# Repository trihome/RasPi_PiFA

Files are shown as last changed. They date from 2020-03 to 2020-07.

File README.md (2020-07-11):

# PiFA HAT

This board will make it possible to connect equipment used at the factory  (ex: switches, sensors, relays, at all...) to your Raspberry Pi.
It can isolate connected equipments from Raspberry Pi.

**Note**

Please import this library before using this repository.
https://github.com/trihome/KiCad_MyLibrary

**How to make**

[Manual (Japanese only)](./doc/README_pcb.jp.md)

## [PiFA 8xy](./PiFA_8xy/)

A prototyping board "HAT".
GPIO pins can be freely selected.

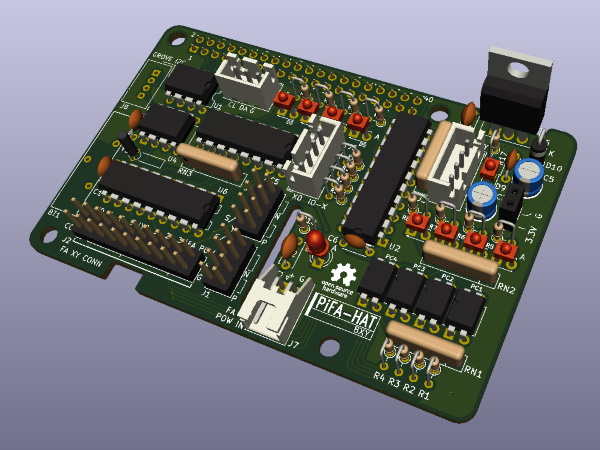
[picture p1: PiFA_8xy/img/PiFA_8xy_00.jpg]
pifa8xy00 3D


- 4 isolated inputs and 4 isolated outputs.
- Selectable Sink(NPN) / Source(PNP)
- I2C-bus voltage-level translator (3.3 to 5 V)
- RTC

## License

This is under [CC-BY-SA](https://creativecommons.org/licenses/by-sa/4.0/).

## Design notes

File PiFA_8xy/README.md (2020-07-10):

# PiFA 8xy

A prototyping board "HAT".

GPIO pins can be freely selected.

[Schematic](./img/PiFA_8xy.pdf)

**Note**

Please import this library before using this repository.
https://github.com/trihome/KiCad_MyLibrary

pifa8xy00 3D
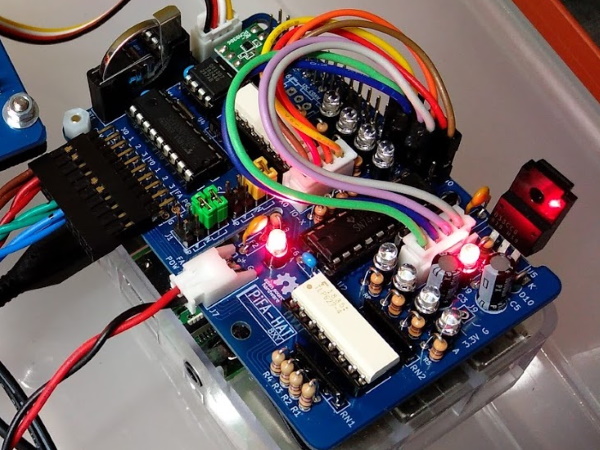
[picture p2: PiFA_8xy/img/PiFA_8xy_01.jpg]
pifa8xy01 Usage


## Spec

- 4 isolated inputs and 4 isolated outputs.
  - J3(Y) is Output, and J5(X) is Input.
  - Connect these connectors to the Raspberry Pi Pins.
  - [J3 and J5: B4B-XH-A(LF)(SN)](http://akizukidenshi.com/catalog/g/gC-12249/)
  - [Raspberry Pi Pins: QI(2550)connectors](http://akizukidenshi.com/catalog/g/gC-12150/)
- Supply 24V power to J7.
  - J2 is Input / Output for FA(24V)
  - Recommended [Terminal block](https://www.togi.co.jp/product/interface/1072/) and [Cables](https://www.togi.co.jp/product/harness-cable/2661/) or QI(2550)connectors.
- Selectable Sink(NPN) / Source(PNP) : J1(Input), J4(Output)
  - U6: Transistor array, you have to choose.
    - J4 = [Sink(NPN)](http://akizukidenshi.com/catalog/g/gI-10669/)
    - J4 = [Source(PNP)](http://akizukidenshi.com/catalog/g/gI-10957/)
- I2C-bus voltage-level translator (3.3 to 5 V)
  - [U1: AE-PCA9306](http://akizukidenshi.com/catalog/g/gM-05452/)
  - I2C Output connector
    - J6: Pin Header (5V)
    - J8: GROVE (5V)
- RTC
  - [U4 : DS1307+](http://akizukidenshi.com/catalog/g/gI-06949/)
  - [BT1: CH243-2032LF](http://akizukidenshi.com/catalog/g/gP-02019/) and CR2032

## Example of use

### Terminal block

- [Terminal block](https://www.togi.co.jp/product/interface/1072/)
- [Cables](https://www.togi.co.jp/product/harness-cable/2661/)

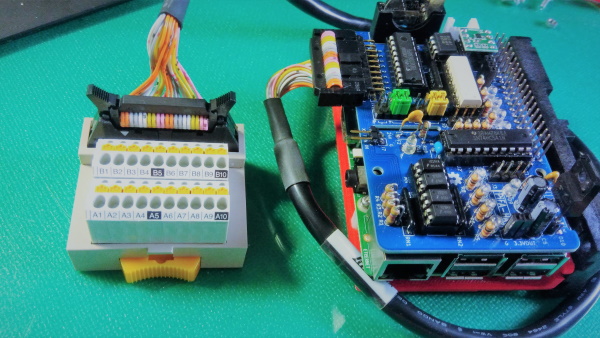
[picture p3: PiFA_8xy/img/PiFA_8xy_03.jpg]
pifa8xy03 Usage

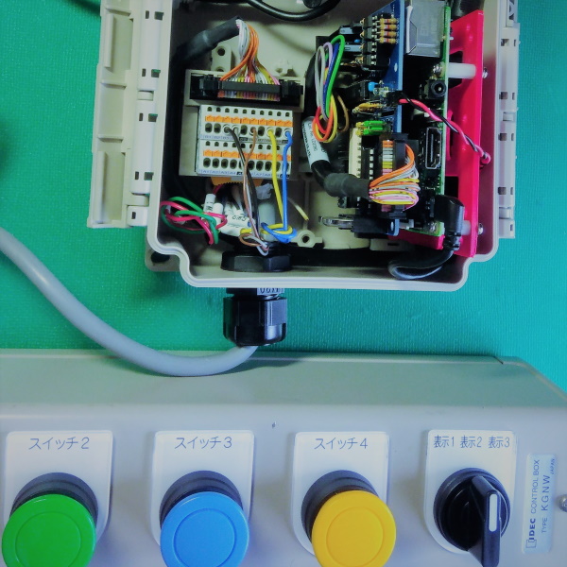
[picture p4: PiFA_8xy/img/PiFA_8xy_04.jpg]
pifa8xy04 Usage


### Stack
If you need more I/O ports, you can increase them by stacking boards.
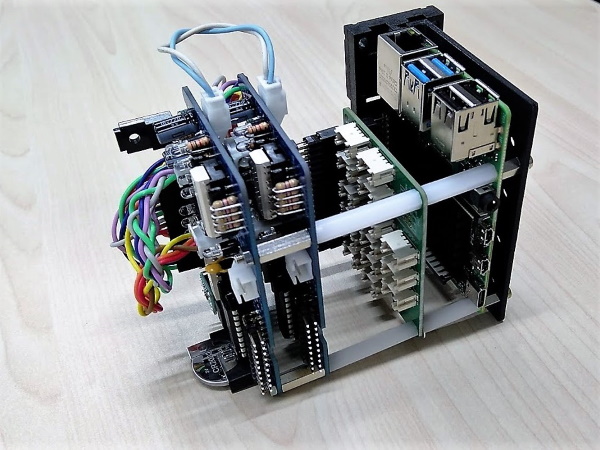
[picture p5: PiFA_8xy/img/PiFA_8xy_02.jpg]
pifa8xy02 Usage

- The board sandwiched in the middle is [Grove Base Hat for Raspberry Pi](http://wiki.seeedstudio.com/Grove_Base_Hat_for_Raspberry_Pi/)
- DIN rail bracket: [example](https://www.takachi-el.co.jp/products/DRA)

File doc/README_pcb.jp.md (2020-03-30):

# 製作方法について

## 部品の入手

大半の部品は、秋月電子通商さんで購入できます。
一部、取り扱いのない部品については、以下から購入可能です。
（端子台などのFA用部品は、勤め先で取引している電材屋さんで購入するのが望ましいです）

|部品名|入手先|通販|
|---|---|---|
|集合抵抗 4P 4.7kΩ|千石電商さん|[リンク](https://www.sengoku.co.jp/mod/sgk_cart/detail.php?code=EEHD-05ST)|
|^|マルツさん|[リンク](https://www.marutsu.co.jp/pc/i/435604/)|
|端子台|マルツさん|[リンク](https://www.marutsu.co.jp/pc/i/1544810/)|
|^|misumiさん|[リンク](https://jp.misumi-ec.com/vona2/detail/222000477644/?HissuCode=PCX-1H20)|
|端子台ケーブル|yahoo shoppingさん|[リンク](https://store.shopping.yahoo.co.jp/akin-do/tao-00009.html)|
||||

## 基板の製作

各ディレクトリ配下に、`gerver`ディレクトリがあるので、この中のファイル一式を、PCB業者に制作依頼します。

（一例）
- [Fusion PCB](https://www.fusionpcb.jp/)
- [P板.com](https://www.p-ban.com/)

### Fusion PCBでの注文手順

※2020年3月時点の手順です。
※費用はPayPalアカウントかクレジットカードで支払います。

1. ユーザー登録
    https://www.fusionpcb.jp/register.html

    [こちら](http://tomokatsu.hatenablog.com/entry/2017/06/14/213324)を参考に、ユーザー登録します。
    
    ※住所は英語表記です。（日本での表記と逆順）

1. gerverディレクトリの中のファイル１０個をZIPで圧縮

1. 発注
    https://www.fusionpcb.jp/fusion_pcb.html

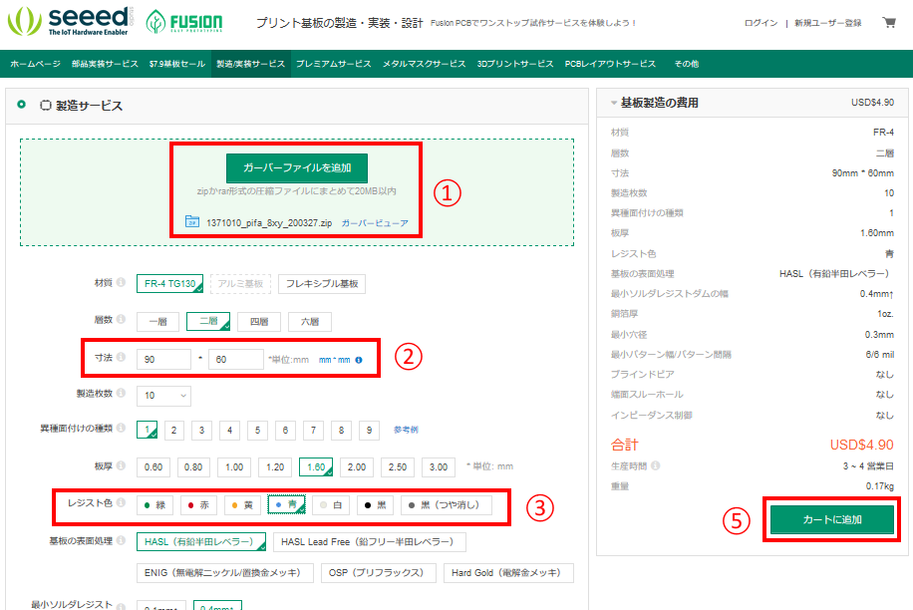
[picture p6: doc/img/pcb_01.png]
pcb01 Usage
    

    1. 「ガーバーファイルを追加」を押して、先ほどのZIPファイルをアップロード
    1. 寸法は 90 x 60 mmを指定
        - 自動で入力される場合もあります
        - 100 x 100 mmサイズ以下かつ、１０枚以下は1ロットの基板費用は$5以下
    1. レジスト色は好きな色を選ぶ（黒つや消しは若干高価）
    1. その他の指定はデフォルトのまま
    1. 「カートに追加」ボタンを押す
    1. カートをクリック
    1. 「お支払いに進む」ボタンを押す
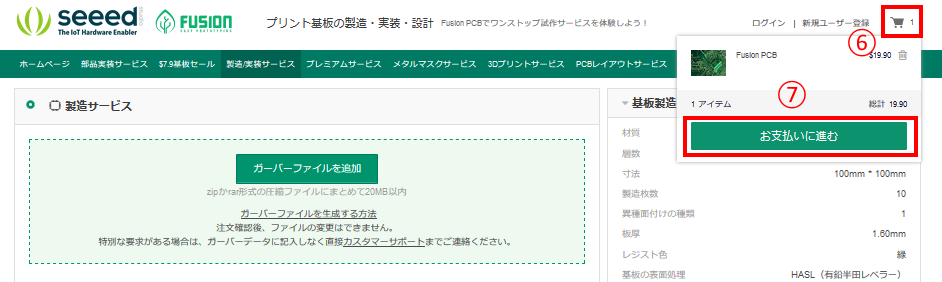
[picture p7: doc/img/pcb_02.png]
    
    1. 「安全な支払いを選択」を押して、（ログインしてない場合は）ここでログイン
    1. 送り先の確認（アカウント情報から紐付けで自動代入）
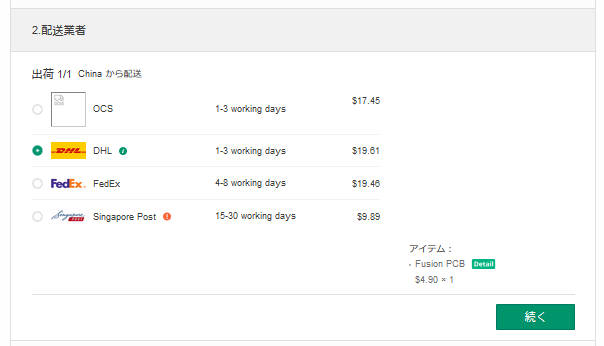
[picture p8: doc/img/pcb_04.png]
    
    1. 配送業者を選ぶ
        - 急ぐときはDHL, FedEx, OCSなどの航空便を選ぶ。送料約$20前後。
    1. 費用を支払う

航空便を使った場合、納期の目安は平常時（中国内での季節のイベントがないとき）で実働5日～10日くらいです。

以上

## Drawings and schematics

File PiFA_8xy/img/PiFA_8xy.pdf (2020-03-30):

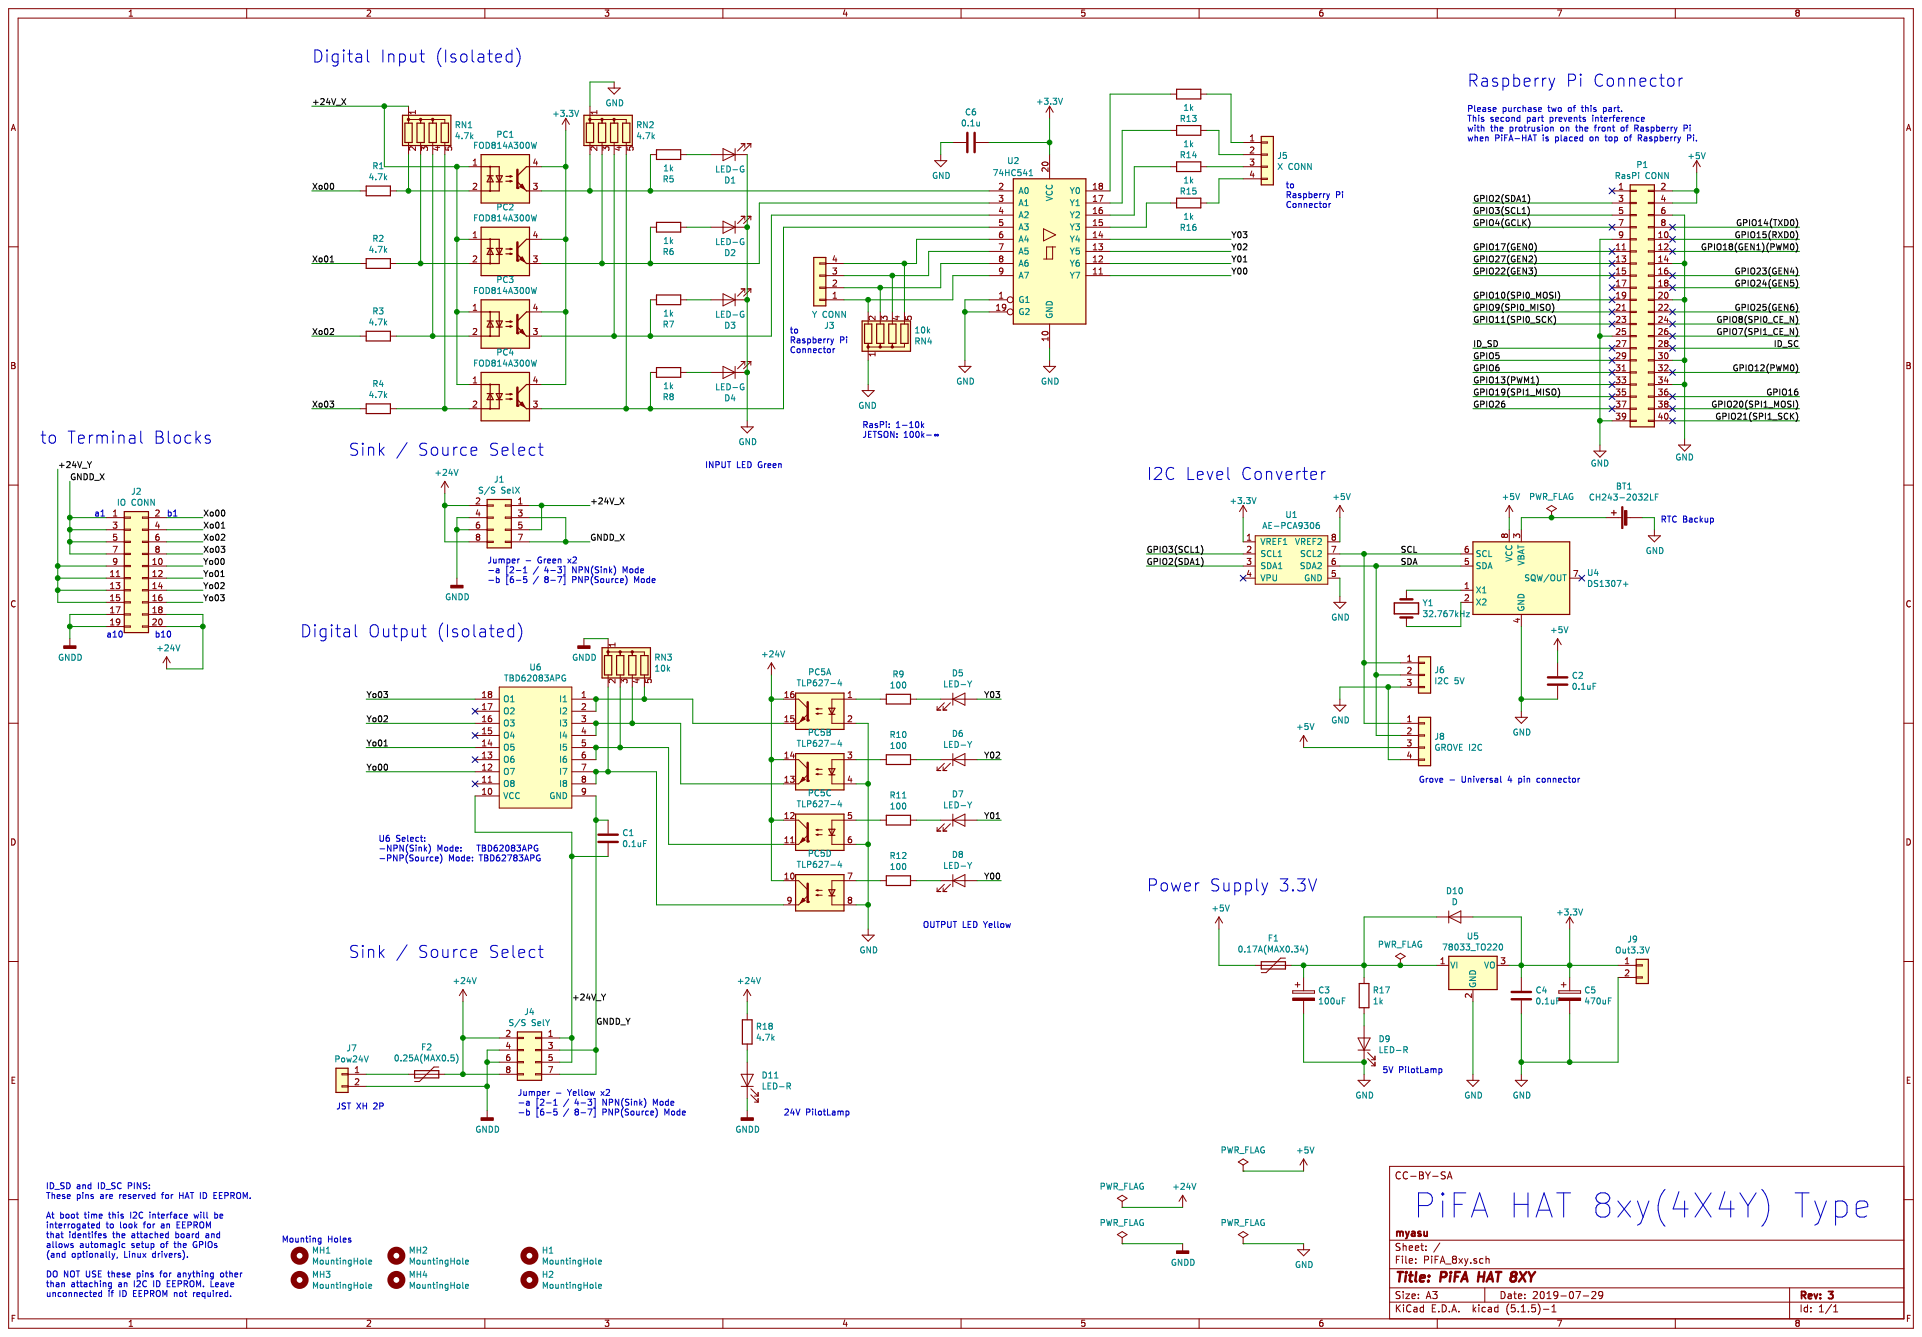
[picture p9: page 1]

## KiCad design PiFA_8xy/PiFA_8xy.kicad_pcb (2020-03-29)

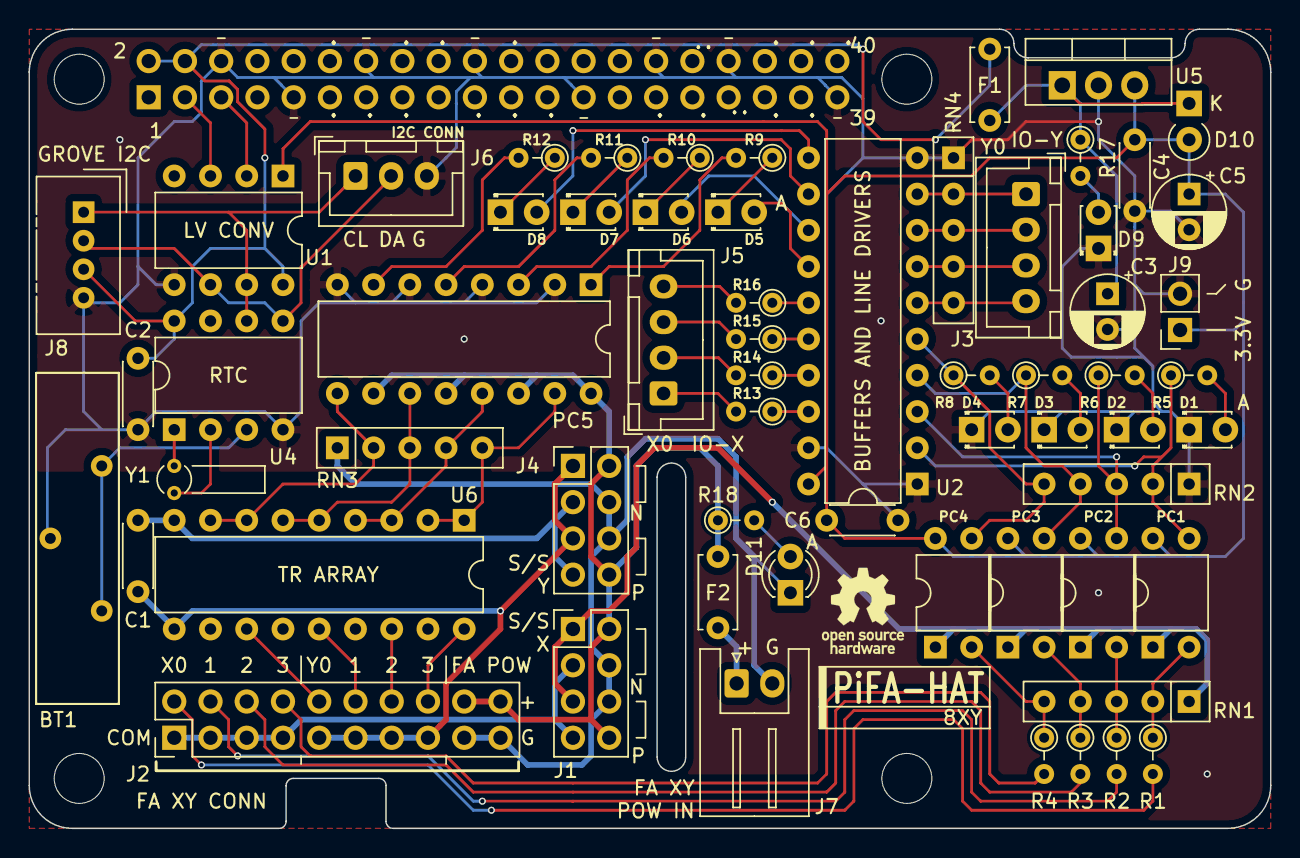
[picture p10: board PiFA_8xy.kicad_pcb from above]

Board: 2 copper layers, 87.0 x 56.0 mm, 69 parts (1 on the bottom side), 68 nets.

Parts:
BT1: CH74-2032LF; BatteryHolder_Keystone_CH74-2032LF
C1, C2, C4: 0.1uF; C_Disc_D4.3mm_W1.9mm_P5.00mm
C3: 100uF; CP_Radial_D5.0mm_P2.50mm
C5: 470uF; CP_Radial_D5.0mm_P2.50mm
C6: 0.1u; C_Disc_D4.3mm_W1.9mm_P5.00mm
D1, D2, D3, D4: LED-G; LED_D1.8mm_W3.3mm_H2.4mm
D5, D6, D7, D8: LED-Y; LED_D1.8mm_W3.3mm_H2.4mm
D9: LED-R; LED_D1.8mm_W3.3mm_H2.4mm
D10: D; D_A-405_P2.54mm_Vertical_KathodeUp
D11: LED-R; LED_D3.0mm
F1: 0.17A(MAX0.34); C_Disc_D5.0mm_W2.5mm_P5.00mm
F2: 0.25A(MAX0.5); C_Disc_D5.0mm_W2.5mm_P5.00mm
H1: MountingHole; OSHW-Logo_5.7x6mm_SilkScreen
H2: MountingHole; CC-BY-SA
J1: S/S SelX; PinHeader_2x04_P2.54mm_Vertical
J2: IO CONN; PinHeader_2x10_P2.54mm_Vertical
J3: Y CONN; JST_XH_B4B-XH-A_1x04_P2.50mm_Vertical
J4: S/S SelY; PinHeader_2x04_P2.54mm_Vertical
J5: X CONN; JST_XH_B4B-XH-A_1x04_P2.50mm_Vertical
J6: I2C 5V; JST_XH_B3B-XH-A_1x03_P2.50mm_Vertical
J7: Pow24V; JST_XH_S2B-XH-A_1x02_P2.50mm_Horizontal
J8: GROVE I2C; NS-Tech_Grove_1x04_P2mm_Vertical
J9: Out3.3V; PinSocket_1x02_P2.54mm_Vertical
MH1, MH2, MH3, MH4: MountingHole; MountingHole_3mm
P1: RasPi CONN; PinSocket_2x20_P2.54mm_Vertical
PC1, PC2, PC3, PC4: FOD814A300W; DIP-4_W7.62mm
PC5: TLP627-4; DIP-16_W7.62mm
R1, R2, R3, R4, R18: 4.7k; R_Axial_DIN0204_L3.6mm_D1.6mm_P2.54mm_Vertical
R5, R6, R7, R8, R13, R14, R15, R16, R17: 1k; R_Axial_DIN0204_L3.6mm_D1.6mm_P2.54mm_Vertical
R9, R10, R11, R12: 100; R_Axial_DIN0204_L3.6mm_D1.6mm_P2.54mm_Vertical
RN1, RN2: 4.7k; R_Array_SIP5
RN3: 10k; R_Array_SIP5
RN4: 1k; R_Array_SIP5
U1: AE-PCA9306; DIP-8_W7.62mm
U2: 74HCT541; DIP-20_W7.62mm
U4: DS1307+; DIP-8_W7.62mm
U5: 78033_TO220; TO-220-3_Vertical
U6: TBD62083APG; DIP-18_W7.62mm
Y1: 32.767kHz; Crystal_Round_D2.0mm_Vertical

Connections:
+3V3: C4.1, C5.1, C6.1, D10.2, J9.1, PC1.4, PC2.4, PC3.4, PC4.4, U1.1, U2.20, U5.3
+5V: C2.1, F1.2, J8.3, P1.2, P1.4, U1.8, U4.8
+24V: F2.1, J1.2, J1.8, J2.18, J2.20, J4.2, J4.8, PC5.10, PC5.12, PC5.14, PC5.16, R18.1
/+24V_X: J1.1, J1.5, PC1.1, PC2.1, PC3.1, PC4.1, RN1.1
/+24V_Y: C1.2, J2.9, J2.11, J2.13, J2.15, J4.1, J4.5, U6.10
/GNDD_X: J1.3, J1.7, J2.1, J2.3, J2.5, J2.7
/GNDD_Y: C1.1, J4.3, J4.7, U6.9
/GPIO2(SDA1): P1.3, U1.3
/GPIO3(SCL1): P1.5, U1.2
/SCL: J6.1, J8.1, U1.7, U4.6
/SDA: J6.2, J8.2, U1.6, U4.5
/Xo00: J2.2, R1.2
/Xo01: J2.4, R2.2
/Xo02: J2.6, R3.2
/Xo03: J2.8, R4.2
/Y00: D8.2, U2.11
/Y01: D7.2, U2.12
/Y02: D6.2, U2.13
/Y03: D5.2, U2.14
/Yo00: J2.10, U6.12
/Yo01: J2.12, U6.14
/Yo02: J2.14, U6.16
/Yo03: J2.16, U6.18
GND: BT1.2, C2.2, C3.2, C4.2, C5.2, C6.2, D1.1, D2.1, D3.1, D4.1, D9.1, J6.3, J8.4, J9.2, P1.6, P1.9, P1.14, P1.20, P1.25, P1.30, P1.34, P1.39, PC5.2, PC5.4, PC5.6, PC5.8, RN2.1, RN4.1, U1.5, U2.1, U2.10, U2.19, U4.4, U5.2
GNDD: D11.1, J1.4, J1.6, J2.17, J2.19, J4.4, J4.6, J7.2, RN3.1
unnamed: BT1.1, U4.3
unnamed: C3.1, D10.1, F1.1, R17.1, U5.1
unnamed: D1.2, R5.2
unnamed: D2.2, R6.2
unnamed: D3.2, R7.2
unnamed: D4.2, R8.2
unnamed: D5.1, R9.1
unnamed: D6.1, R10.1
unnamed: D7.1, R11.1
unnamed: D8.1, R12.1
unnamed: D9.2, R17.2
unnamed: D11.2, R18.2
unnamed: F2.2, J7.1
unnamed: J3.1, RN4.2, U2.9
unnamed: J3.2, RN4.3, U2.8
unnamed: J3.3, RN4.4, U2.7
unnamed: J3.4, RN4.5, U2.6
unnamed: J5.1, R13.2
unnamed: J5.2, R14.2
unnamed: J5.3, R15.2
unnamed: J5.4, R16.2
unnamed: PC1.2, R1.1, RN1.2
unnamed: PC1.3, R5.1, RN2.2, U2.2
unnamed: PC2.2, R2.1, RN1.3
unnamed: PC2.3, R6.1, RN2.3, U2.3
unnamed: PC3.2, R3.1, RN1.4
unnamed: PC3.3, R7.1, RN2.4, U2.4
unnamed: PC4.2, R4.1, RN1.5
unnamed: PC4.3, R8.1, RN2.5, U2.5
unnamed: PC5.1, R9.2
unnamed: PC5.3, R10.2
unnamed: PC5.5, R11.2
unnamed: PC5.7, R12.2
unnamed: PC5.9, RN3.2, U6.7, U6.8
unnamed: PC5.11, RN3.3, U6.5, U6.6
unnamed: PC5.13, RN3.4, U6.3, U6.4
unnamed: PC5.15, RN3.5, U6.1, U6.2
unnamed: R13.1, U2.18
unnamed: R14.1, U2.17
unnamed: R15.1, U2.16
unnamed: R16.1, U2.15
unnamed: U4.1, Y1.1
unnamed: U4.2, Y1.2

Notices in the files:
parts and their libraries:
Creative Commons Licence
